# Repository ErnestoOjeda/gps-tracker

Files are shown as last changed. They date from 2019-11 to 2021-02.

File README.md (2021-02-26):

# wander-hardware

### Overview

The Wander v1.1 prototype is an adaptation of the Particle LTE line of industrialized cellular IoT modules. It is based on the Particle E-Series LTE module and includes an onboard GPS module based on the MTK-3339 chipset.

### Description

#### Front

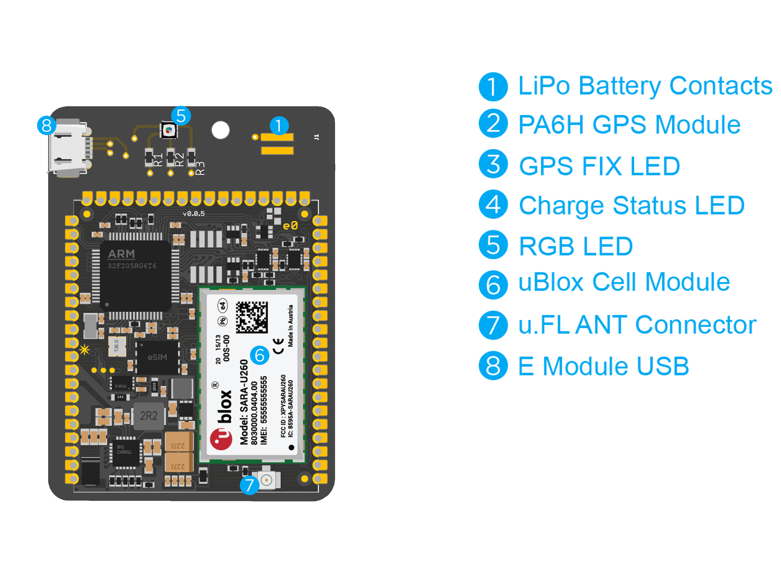
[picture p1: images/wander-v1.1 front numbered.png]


#### Back

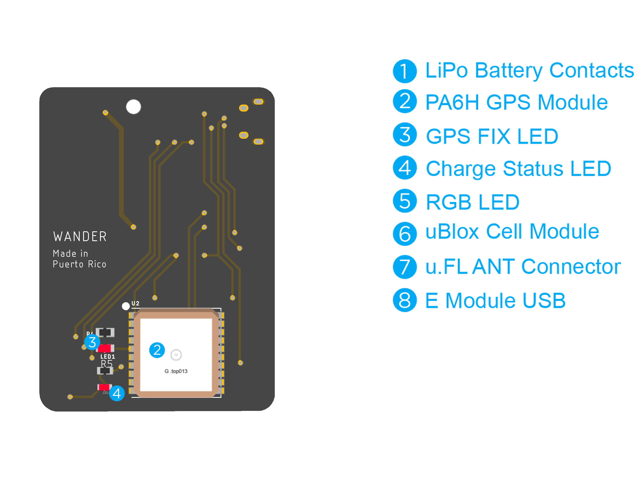
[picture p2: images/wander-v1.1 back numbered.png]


| ID 					 | Description |
|:---|:---|
| **LiPo Battery Contacts** | This is directly connected to the LIPO pin. The recommended input voltage range on this pin is between 3.6V to 4.4VDC. Make sure that the battery can handle currents of at least 3Amp.  |
| **PA6H GPS module** |MTK-3339-based GPS module that can track up to 22 satellites on 66 channels, with an excellent -165 dB sensitivity receiver, and a built in antenna.|
| **GPS FIX LED** | This LED blinks at about 1Hz while it's searching for satellites and blinks once every 15 seconds when a fix is found to conserve power.|
| **Charge status LED** | Pretty self-explanatory.|
| **RGB LED** | Displays cellular connectivity status.|
| **u-blox cell module** | This is the u-blox SARA module.|
| **uFl antenna connector** |Plug the antenna here. |
| **E Module USB port** | This is the module's microUSB port that connects to the STM32F microcontroller.|

### Components List

* u-blox SARA R410M LTE modem
  * LTE CAT M1/ NB1 module with global hardware support
  * 3GPP Release 13 LTE Cat M1
* MediaTek MTK3339
  * SBAS, Galileo, GLONASS, GPS / QZSS
  * Supports WAAS/EGNOS/MSAS/GAGAN
  * 22 tracking / 66 acquisition-channel GPS receiver
* STMElectronics LSM303ADRTR
  * 3 magnetic field channels and 3 acceleration channels
  * Embedded temperature sensor
* STMicroelectronics STM32F205RGT6 
  * 120MHz ARM Cortex M3 microcontroller
  * 1MB flash, 128KB RAM 
  * Supports DSP instructions, hardware accelerated FPU calculations 
* MAX17043 fuel gauge
* Micro USB 2.0 full speed (12 Mbps)
* FCC and PTCRB certified
* RoHS compliant (lead-free)

### Structure of this Repository
 - /bom
     + Contains the electronics bill of materials outlining the components used
 - /cad-cases
     + Contains .f3d files for various looks-like/works-like case designs
 - /datasheets
     + Contains the relevant datasheets of the components used
 - /documentation
     + Contains prototype PRD and Working Specification & Requirements sheets
 - /eagle
     + Contains the schematic and PCB files in the Eagle file format
 - /gerbers
     + Contains PCB gerber files for manufacturing
 - /images
     + Contains the images used in the description

### Change Log
#### v1.1.0 (LATEST)
* initial beta release

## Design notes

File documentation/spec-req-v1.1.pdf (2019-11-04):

# Wander v1.1 Prototype Sheet

Wander Team 2019

# Requirements

## - Commercial/Regions/Regulatory

- COGS $200; sold in US and Canada. FCC (active emitter), IC, PTCRB, CE, RoHS LeadFree

## - Hardware/Sensors

- Block diagram, major BOM components; sensor requirements (accelerometer)

## - Electronics/Power/Battery

- PCB must be no larger than 100mm x 36mm, 2K EEPROM; no more than 1.8A transients at 5VDC, 130uA in deep sleep; max battery runtime 11 days in deep sleep, LiPo, no larger than 51mm x 34mm x 9mm

## - Firmware/API/Libraries

- Operating System (Device OS), OTA updates (Particle Cloud); CoAP over DTLS over UDP; RSA used for authentication

## - Software/Web/Cloud

- Device Cloud, Google Firebase

## - Mechanical/Plastics/Logos/Packaging

- PA-12 enclosure; Wander logo embossed onto enclosure surface

## - Environmental/ Dimensions/Service

- Operating ambient temperature -20C-60C, 0% - 95% RH; 80mm x 45mm x 15mm; no field service, issues will be resolved in-house as refurbish

# Specifications

## - Installed System Life

- N/A

## - Operating Temperature Range

- -40 to 85C E-Series; -40 to 85C PA6H; -20 to 60C LiPo Battery

## - Dimensions

- Main Housing
■ 80mm x 45mm x 20mm
- PCB
■ 58mm x 42mm x 11mm
- Battery
■ 41mm x 41mm x 6mm

## - Weight

- TBD

## - On-Board GPS

- 66-channel, MTK3339-based module
- GPS/QZSS L1 C/A, GLONASS L10F, BeiDou B1I, Galileo E1B/C, SBAS L1 C/A: WAAS, EGNOS, MSAS, GAGAN
- Update rates: Single GNSS: up to 10 Hz, 2 Concurrent GNSS: up to 10 Hz
- -165dBm sensitivity; 20mA current draw; 1.8m position accuracy
- Acquisition times: Cold starts: 34s, Aided starts: 2s, Reacquisition: 1s

## - Battery

- Runtime: 28h
- Cell Chemistry: Rechargeable Lithium Ion Polymer (Lithium Systems)
- Polymer Cell Electrolyte: Gel Polymer
- Dimensions: 41mm x 41mm x 6mm
- Capacity: 1080mAh; JP604141

## - Power

- USB: Max 500mA supply
- VIN: 3.9VDC to 12VDC, rated 10W
- LiPo: 180mA, upto 550mA transients. Deep sleep mode at 110uA

## - Field Strategy

- Not field serviceable
- RMA strategy not necessary, test units will be swapped out for working units
- No reset button

## - Wireless Firmware Update

- Done OTA on the Particle Device Cloud

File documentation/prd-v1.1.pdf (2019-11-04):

### Product Requirements Document (v1.1)

### OVERVIEW

Product Description

Market Need | Parents with children too young to own a cell phone can get location information and notifications-based insight of their children’s whereabouts while on vacation. Currently-available solutions are either expensive, require ownership & data-contracts, or impractical.
Key Features/ Functionality | GPS-over-cellular and location analytics coupled with human-based notifications that offers: ● Out-of-the-box connectivity ● App-based or notification-based location ● Insights into child’s location history
Other Product Compatibility, Ecosystem, etc. | ● Cellular Connectivity ● GNSS Compatibility ● Mobile App ● Manual sources of information (humans)

Stakeholders

Target User | Children ages 4 to 10 years old, the elderly, and people looking to track their assets while out on vacation.
Target Purchaser (if different from user) | Parents, Guardians, Owners/Proprietors
Other Stakeholders | TBD

### COMMERCIALS AND REGULATORY

Countries of Sale | United States
Target Launch Date | Q4 2019

Regulatory Requirements

Safety (UL, CE) | Battery operated -- not required
Emissions (FCC, CE) | Pre-certified Modules ● uBlox SARA R410M ● Generic MTK3339
Interoperability (Cellular, WiFi) | Cellular LTE-M

Labeling

Regulatory Marks | FCC; identifier displayed on cellular module
Country of Origin | Made in China
Serial Number | Serial Number with QR code displayed on cellular module

Financials

BOM Cost | N/A
COGs | $196.80
MSRP | Free; on a rental-by-the-hour basis
Acceptable Margin | 55% target margin; $26,000 target P/L per Device

Volume

MOQ of First Production Run | 10
Annual Volume | N/A
Timeline for Product Refresh (EOL) | 2 to 3 weeks depending on testing outcome and user feedback

### ENVIRONMENT

Storage Environment

Temperature Range | -30C to 75C
Humidity Range | 0% to 95% RH

Operating Environment

Indoor, Outdoor, Wearable | Indoor, Outdoor, Contained Unit
Temperature Range | -40C to 85C
Humidity Range | 0% to 95% RH

### INDUSTRIAL DESIGN

Brand | Push a button, find your kid.

Picture

Color, Material, and Finish (CMF) | Nylon 12 -- (gray, dyed)
Logo size and placement | Embossed into top surface of the enclosure
Connectors (Power, USB, Lighting, Audio) | Micro-USB
Visual Interface (Screen size and type, LEDs) | Red charging LED, RGB status LED, red GPS FIX LED
Touch Interface (Mechanical actuators/switches, touch sensitivity, haptics) | None
Audio Interface (Microphones, speakers) | None

### SOFTWARE ARCHITECTURE AND DATA PROCESSING

Block Diagram of Data Flow

### ELECTRICAL HARDWARE AND SENSORS

Block Diagram of Electrical Hardware

Input/Sensor Requirements | None
Output/Actuator Requirements | None
Critical BOM Components | ● Cellular Module ● GNSS Module ● Battery
Communication Requirements | CoAP over DTLS over UDP; 397ms round-trip
Power Requirements | ● Rechargeable Li-Poly Battery ● 28hr Runtime ● 1080mAh

### DURABILITY

Lifetime requirements | 3500 uses; ~4 years
Cycles of various sub-systems | ≥ 500 battery charge cycles
Chemical Resistance | Superior (PA12)
UV resistance (sunlight) | Superior (PA12)
Environmental (Dust, Water, etc.) | IP68
Mechanical (Drop, Vibration, Abrasion, etc.) | The device must withstand a fall from 15ft onto concrete in six different orientations

### PACKAGING

In the Box | ● Pre-assembled E-Series LTE + Adafruit GPS MTK339 ● Battery (1080mAh) ● Taoglas Ultra Wide Band Antenna
Unboxing Experience | No packaging and custom installation necessary
Printing, colors, inserts, cardboard type, drop requirements | None
Retail Requirements | N/A (sold at kiosk)
SKU Combinations | 1

### SERVICEABILITY

Repair Services | Full replacement handled by the team
Returns Process | Users can contact the team for any grievances regarding the product
Repair/Return Qualifications/Tolerances | Faulty product is subject to replacement and refurbishment
Customer Support System | Phone, text, or email

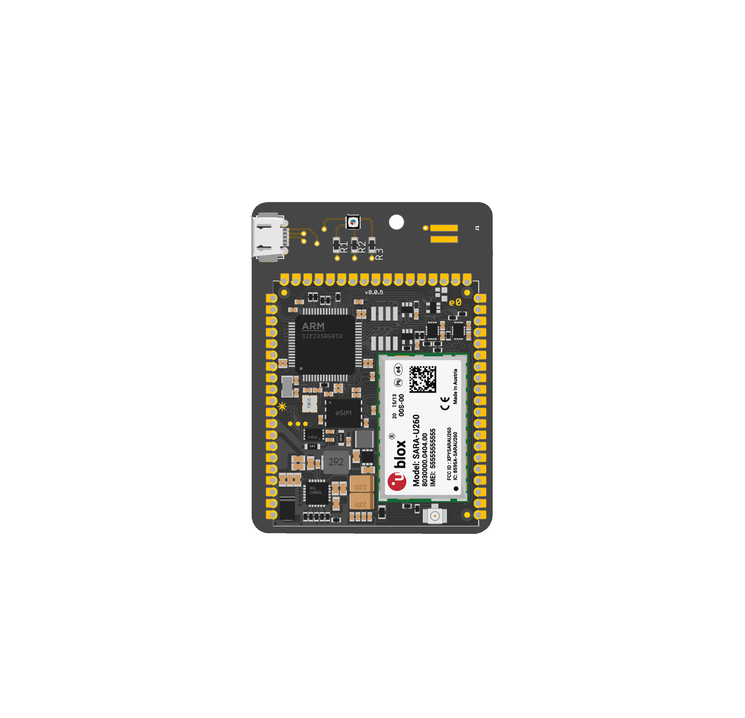
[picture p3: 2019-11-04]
images/wander-v1.1 front.png

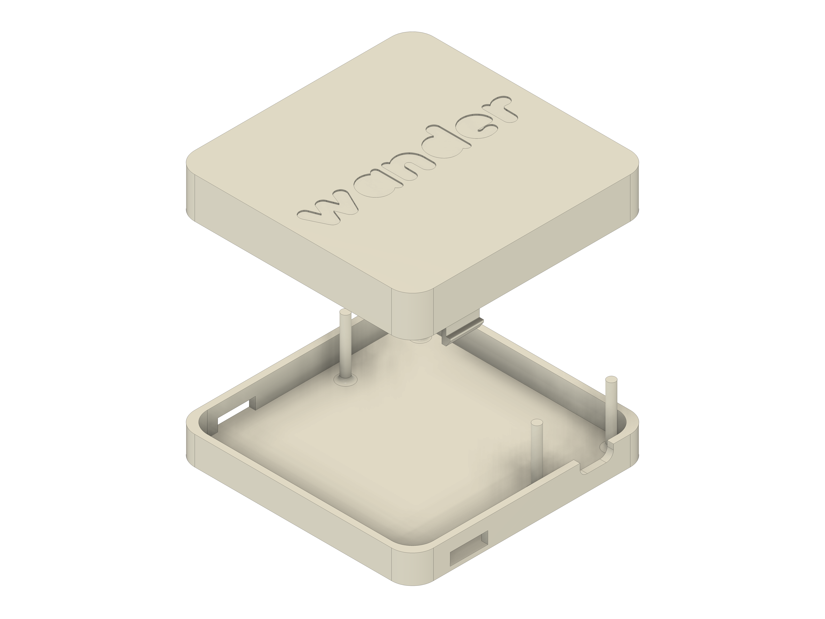
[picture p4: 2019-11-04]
cad/cases/wl-3/wander-wl3.png

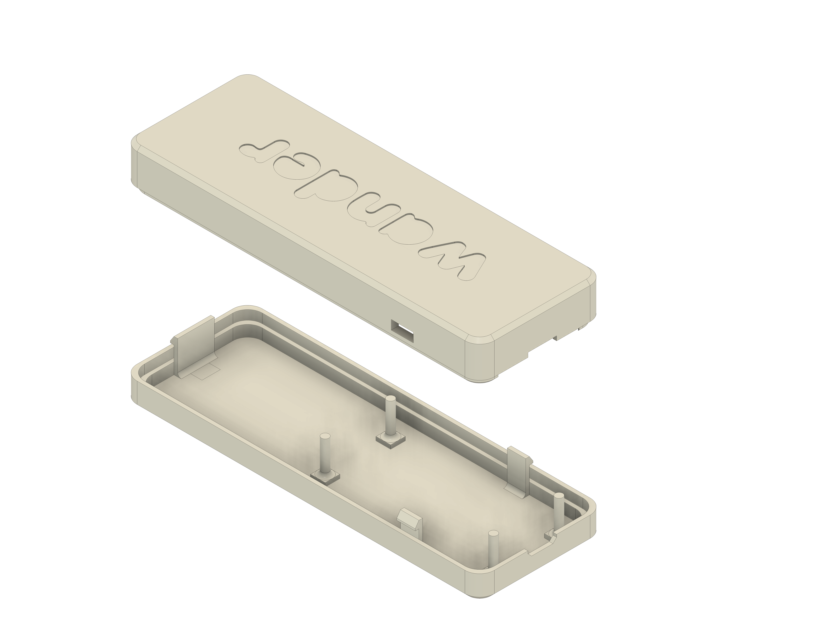
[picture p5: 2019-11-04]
cad/cases/wl-1/wander-wl1.png

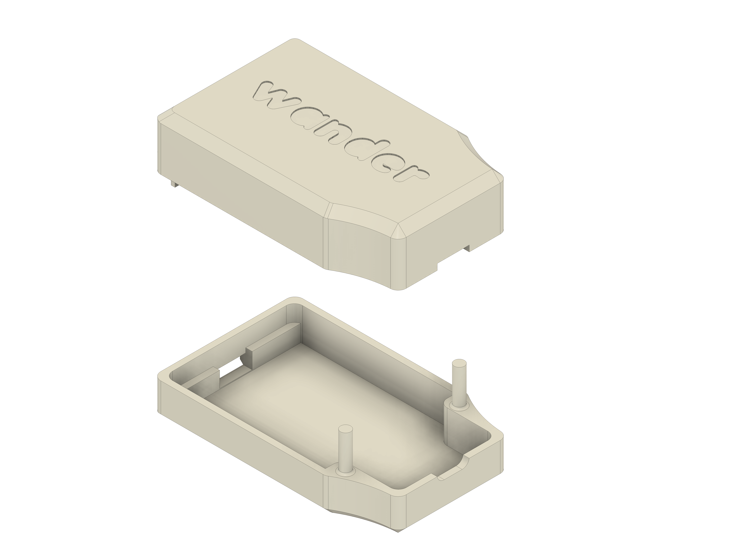
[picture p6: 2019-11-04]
cad/cases/wl-2/wander-wl2.png

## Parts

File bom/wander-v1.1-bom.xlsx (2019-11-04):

IDENTIFIER | DESCRIPTION | VALUE | V | A | W | TOL | PACKAGE ID | DESIGNATOR | QTY | MANUFACTURER | MANUFACTURER P/N | NOTES
CONNECTOR | LIPO BATTERY CONNECTOR |  |  |  |  |  | JST-2-SMD | J1 | 1 | KAWEEI | CW2001-02T1-H01-D
CONNECTOR | MICRO USB CONNECTOR |  |  |  |  |  |  | X1 | 1 | KAWEEI | CMCUSB-5BFM14X-01-X
LED | LED | RED LED |  |  |  |  |  | LED1 | 1 | OSRAM | LS M67K-H2L1-1-Z
LED | LED | RED LED |  |  |  |  |  | LED2 | 1 | EVERLIGHT | 19-217/R6C-AL1M2VY/3T
LED | RGB-LED-CLMVB-FKARGB | RGB LED |  |  |  |  | 4-PLCC (3.2 mm x 2.8mm) | U$6 | 1 | CREE | CLMVB-FKA-CFHEHLCBB7A363
RESISTOR | RESISTOR | 470 OHM |  |  |  | 1% |  | R4 | 1 | Panasonic | ERJ-6ENF4700V
RESISTOR | RESISTOR | 1K |  |  |  | 5% | 603 | R1, R2, R3, R5 | 4 | Unihom | RS-03K102JT

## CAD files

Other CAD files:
cad/cases/wl-1/wander-wl1.f3d
cad/cases/wl-2/wander-wl2.f3d
cad/cases/wl-3/wander-wl3.f3d

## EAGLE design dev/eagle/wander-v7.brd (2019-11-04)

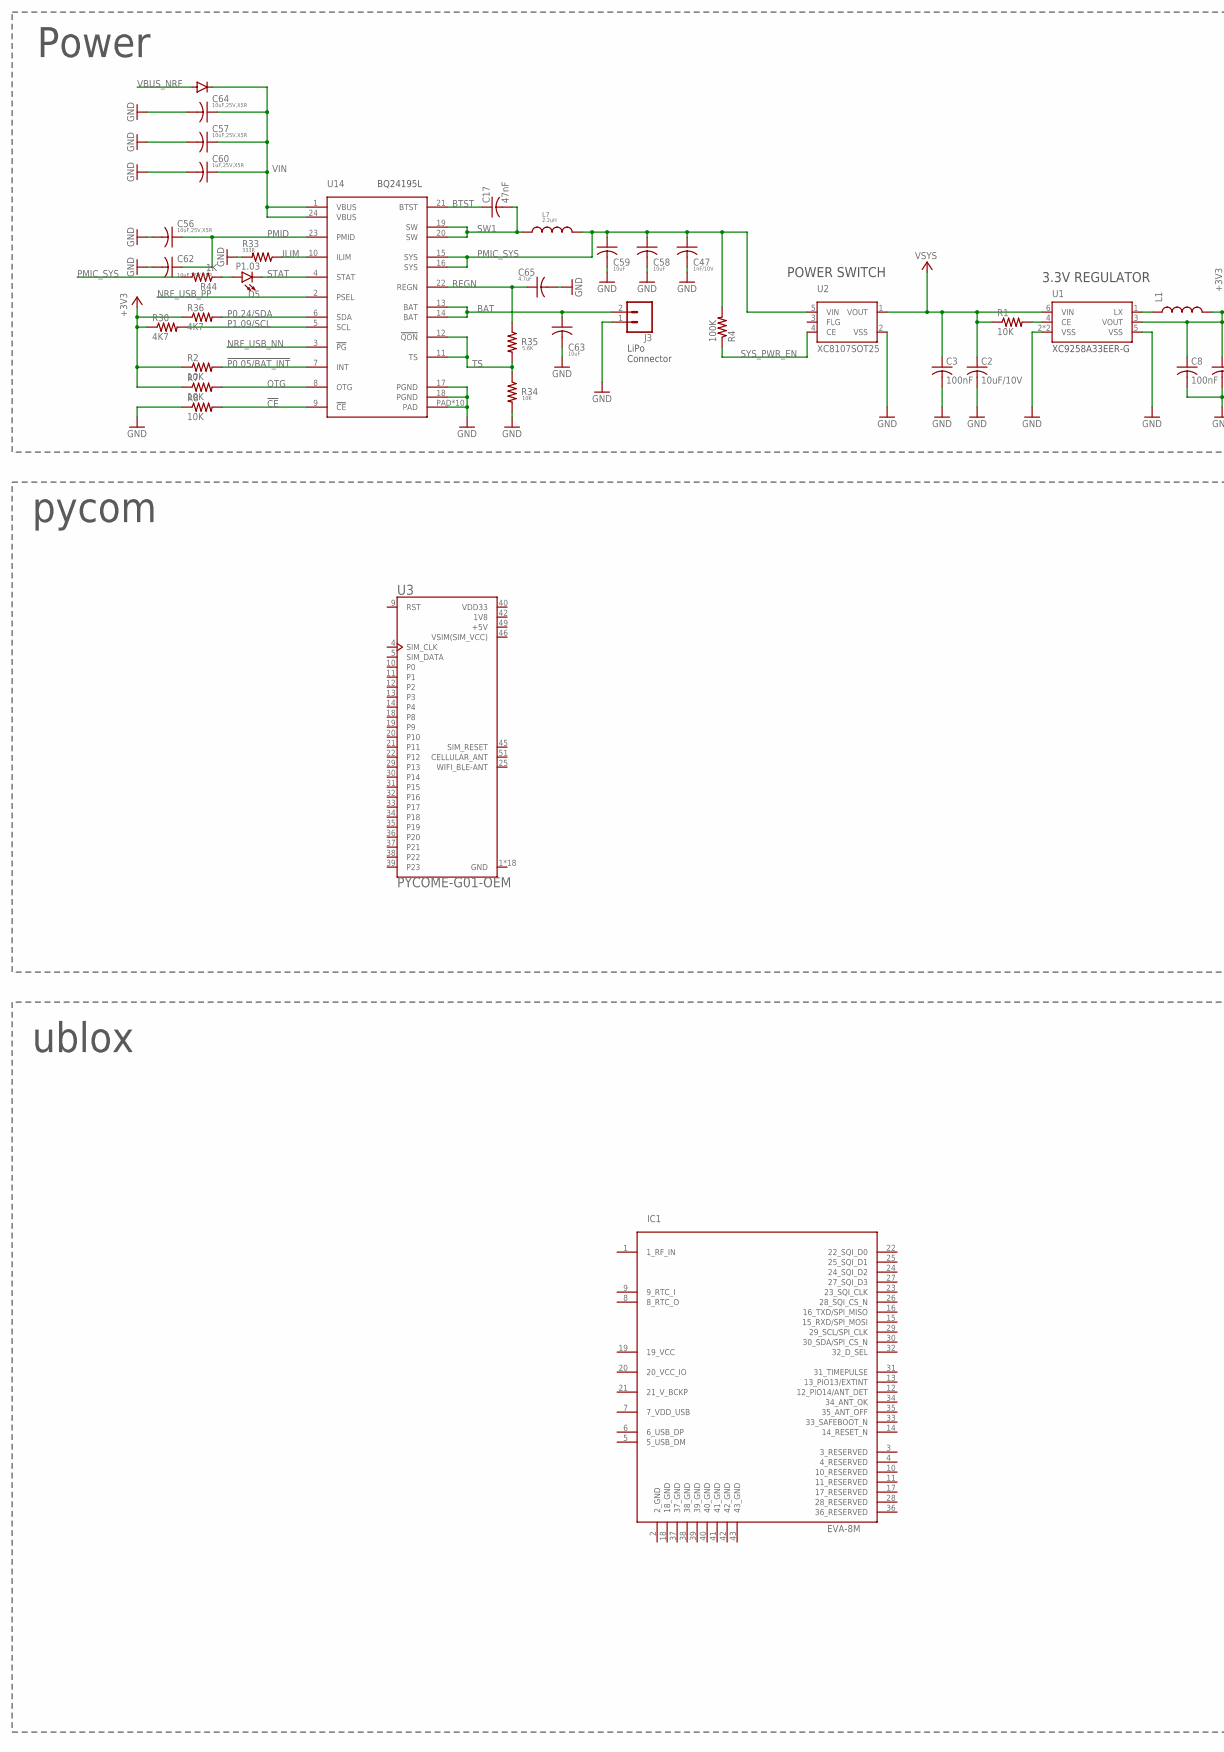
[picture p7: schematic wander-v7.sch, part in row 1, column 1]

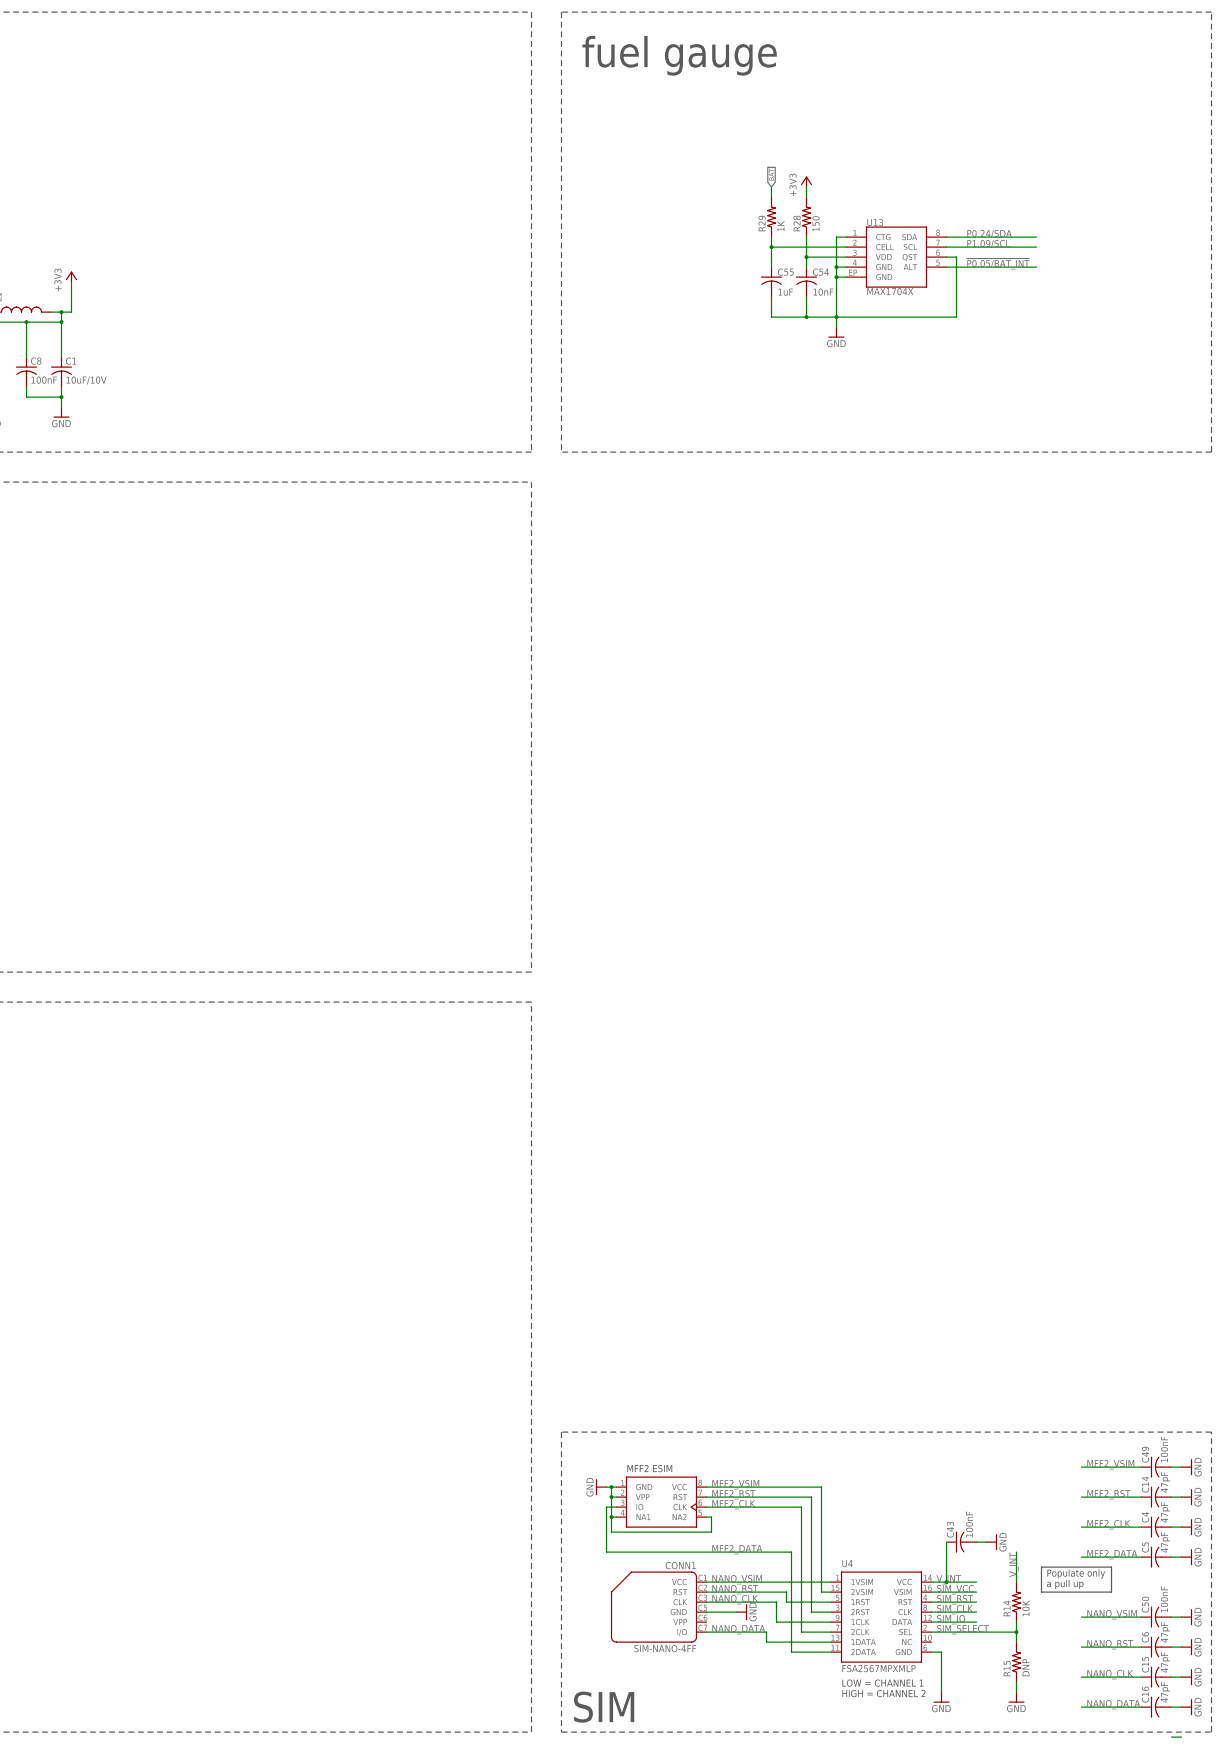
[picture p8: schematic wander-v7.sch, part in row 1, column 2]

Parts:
C1, C2: 10uF/10V; C0603K
C3: 100nF; C0603K
C4, C5, C6, C14, C15, C16: 47pF; C0201_B
C8, C43, C49, C50: 100nF; C0201_B
C17: 47nF; C0201_B
C47: 1nF/10V; C0402_B
C54: 10nF; C0402_B
C55: 1uF; C0402_B
C56, C57, C62, C64: 10uF,25V,X5R; C0603_B
C58, C59, C63: 10uF; C0603_B
C60: 1uF,25V,X5R; C0603_B
C65: 4.7uF; C0603_B
CONN1: SIM-NANO-4FF; GCT-SIM8100
D4: DIODE_NT; DIODE-DO-220AA_NT(SMP)
D5: P1.03; LED-0603
IC1: EVA-8M
J3: CONN_02-JST-2MM-SMT; JST-2-SMD@2
L1: INDUCTOR-SPARKFUNVLS3012ET-4R7M; INDUCTOR-VLS-E
L7: 2.2uH; INDUCTOR-4040
R1, R2, R7, R8, R14: 10K; C0201_B
R4: 100K; C0201_B
R15: DNP; C0201_B
R28: 150; 0402-RES
R29: 1K; 0402-RES
R30, R36: 4K7; C0201_B
R33: 333R; R0402_B
R34: 10K; R0402_B
R35: 5.6K; R0402_B
R44: 1K; C0201_B
U1: XC9258A33EER-G; USP-6C
U2: XC8107SOT25; SOT25
U3: PYCOME-G01-OEM; PYCOM_PYCOME-G01-OEM
U4: FSA2567MPXMLP; MLP16
U7: ESIMSON8; MFF2
U13: MAX1704X; TDFN-8
U14: BQ24195L; QFN24

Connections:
1V8: U3.42 (1V8)
!CE: R8.2, U14.9 (!CE)
!P0.05/BAT_INT: R2.2, U13.5 (ALT), U14.7 (INT)
+3V3: C1.1, C8.1, L1.P$2 (2), R2.1, R7.1, R28.2, R30.1, R36.1, U1.3 (VOUT)
+5V: U3.49 (+5V)
BAT: C63.1, J3.2 (1), R29.2, U14.13 (BAT), U14.14 (BAT)
BTST: C17.1, U14.21 (BTST)
GND: C1.2, C2.2, C3.2, C4.2, C5.2, C6.2, C8.2, C14.2, C15.2, C16.2, C43.2, C47.2, C49.2, C50.2, C54.2, C55.2, C56.2, C57.2, C58.2, C59.2, C60.2, C62.2, C63.2, C64.2, C65.2, CONN1.C5 (GND), J3.1 (2), R8.1, R15.1, R33.2, R34.2, U1.2 (VSS), U1.5 (VSS), U1.P$1 (VSS), U2.2 (VSS), U3.1 (GND), U3.2 (GND), U3.3 (GND), U3.6 (GND), U3.7 (GND), U3.8 (GND), U3.23 (GND), U3.24 (GND), U3.26 (GND), U3.27 (GND), U3.28 (GND), U3.41 (GND), U3.43 (GND), U3.44 (GND), U3.47 (GND), U3.48 (GND), U3.50 (GND), U3.52 (GND), U4.6 (GND), U7.1 (GND), U7.2 (VPP), U7.4 (NA1), U7.5 (NA2), U13.1 (CTG), U13.4 (GND), U13.6 (QST), U13.EP (GND), U14.17 (PGND), U14.18 (PGND), U14.PAD, U14.PAD@1 (PAD), U14.PAD@2 (PAD), U14.PAD@3 (PAD), U14.PAD@4 (PAD), U14.PAD@5 (PAD), U14.PAD@6 (PAD), U14.PAD@7 (PAD), U14.PAD@8 (PAD), U14.PAD@9 (PAD)
ILIM: R33.1, U14.10 (ILIM)
MFF2_CLK: C4.1, U4.7 (2CLK), U7.6 (CLK)
MFF2_DATA: C5.1, U4.11 (2DATA), U7.3 (IO)
MFF2_RST: C14.1, U4.3 (2RST), U7.7 (RST)
MFF2_VSIM: C49.1, U4.15 (2VSIM), U7.8 (VCC)
unnamed: D5.A, R44.1
unnamed: R1.2, U1.4 (CE)
unnamed: L1.P$1 (1), U1.1 (LX)
unnamed: C54.1, R28.1, U13.3 (VDD)
unnamed: C55.1, R29.1, U13.2 (CELL)
NANO_CLK: C15.1, CONN1.C3 (CLK), U4.9 (1CLK)
NANO_DATA: C16.1, CONN1.C7 (I/O), U4.13 (1DATA)
NANO_RST: C6.1, CONN1.C2 (RST), U4.5 (1RST)
NANO_VSIM: C50.1, CONN1.C1 (VCC), U4.1 (1VSIM)
NRF_USB_NN: U14.3 (!PG)
NRF_USB_PP: U14.2 (PSEL)
OTG: R7.2, U14.8 (OTG)
P0.24/SDA: R36.2, U13.8 (SDA), U14.6 (SDA)
P1.09/SCL: R30.2, U13.7 (SCL), U14.5 (SCL)
PMIC_SYS: C47.1, C58.1, C59.1, L7.P$2 (2), R4.2, R44.2, U2.5 (VIN), U14.15 (SYS), U14.16 (SYS)
PMID: C56.1, C62.1, U14.23 (PMID)
REGN: C65.1, R35.1, U14.22 (REGN)
SIM_CLK: U4.8 (CLK)
SIM_IO: U4.12 (DATA)
SIM_RST: U4.4 (RST)
SIM_SELECT: R14.1, R15.2, U4.2 (SEL)
SIM_VCC: U4.16 (VSIM)
STAT: D5.C, U14.4 (STAT)
SW1: C17.2, L7.P$1 (1), U14.19 (SW), U14.20 (SW)
SYS_PWR_EN: R4.1, U2.4 (CE)
TS: R34.1, R35.2, U14.11 (TS), U14.12 (!QON)
VBUS_NRF: D4.ANODE
VDD33: U3.40 (VDD33)
VIN: C57.1, C60.1, C64.1, D4.CATHODE, U14.1 (VBUS), U14.24 (VBUS)
VSIM(SIM_VCC): U3.46 (VSIM(SIM_VCC))
VSYS: C2.1, C3.1, R1.1, U1.6 (VIN), U2.1 (VOUT)
V_INT: C43.1, R14.2, U4.14 (VCC)

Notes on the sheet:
MFF2 ESIM
Populate only a pull up
3.3V REGULATOR
LiPo Connector
ublox
pycom
Power
SIM
fuel gauge
LOW = CHANNEL 1 HIGH = CHANNEL 2
POWER SWITCH

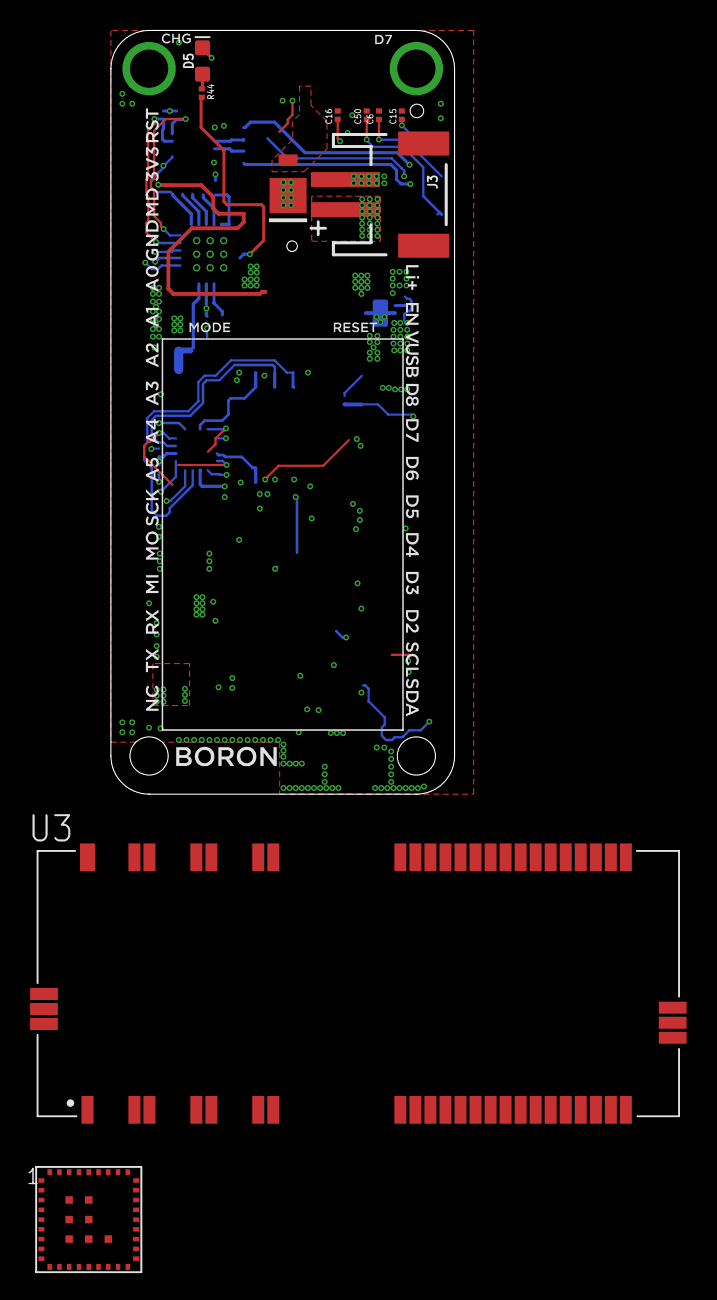
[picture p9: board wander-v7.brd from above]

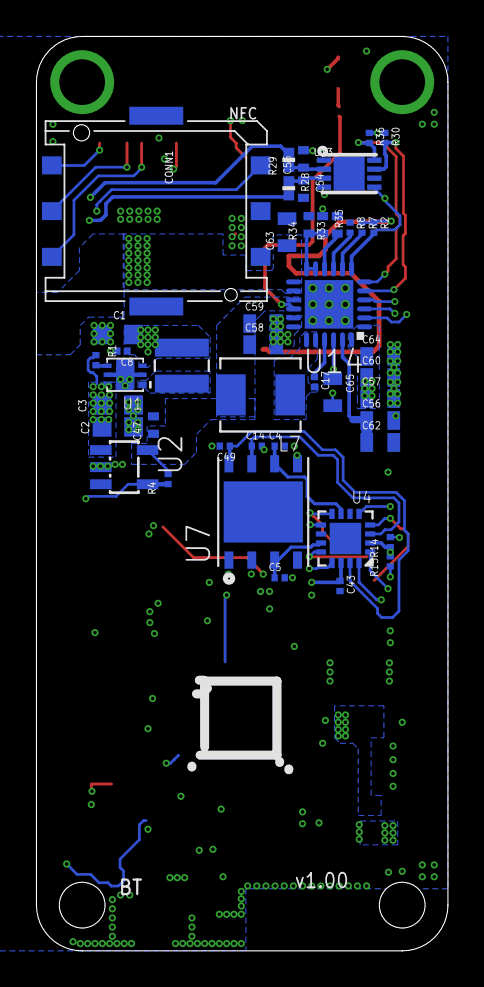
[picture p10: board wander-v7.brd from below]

Board: 8 copper layers, 22.9 x 50.8 mm, 55 parts (45 on the bottom side), 34 nets.

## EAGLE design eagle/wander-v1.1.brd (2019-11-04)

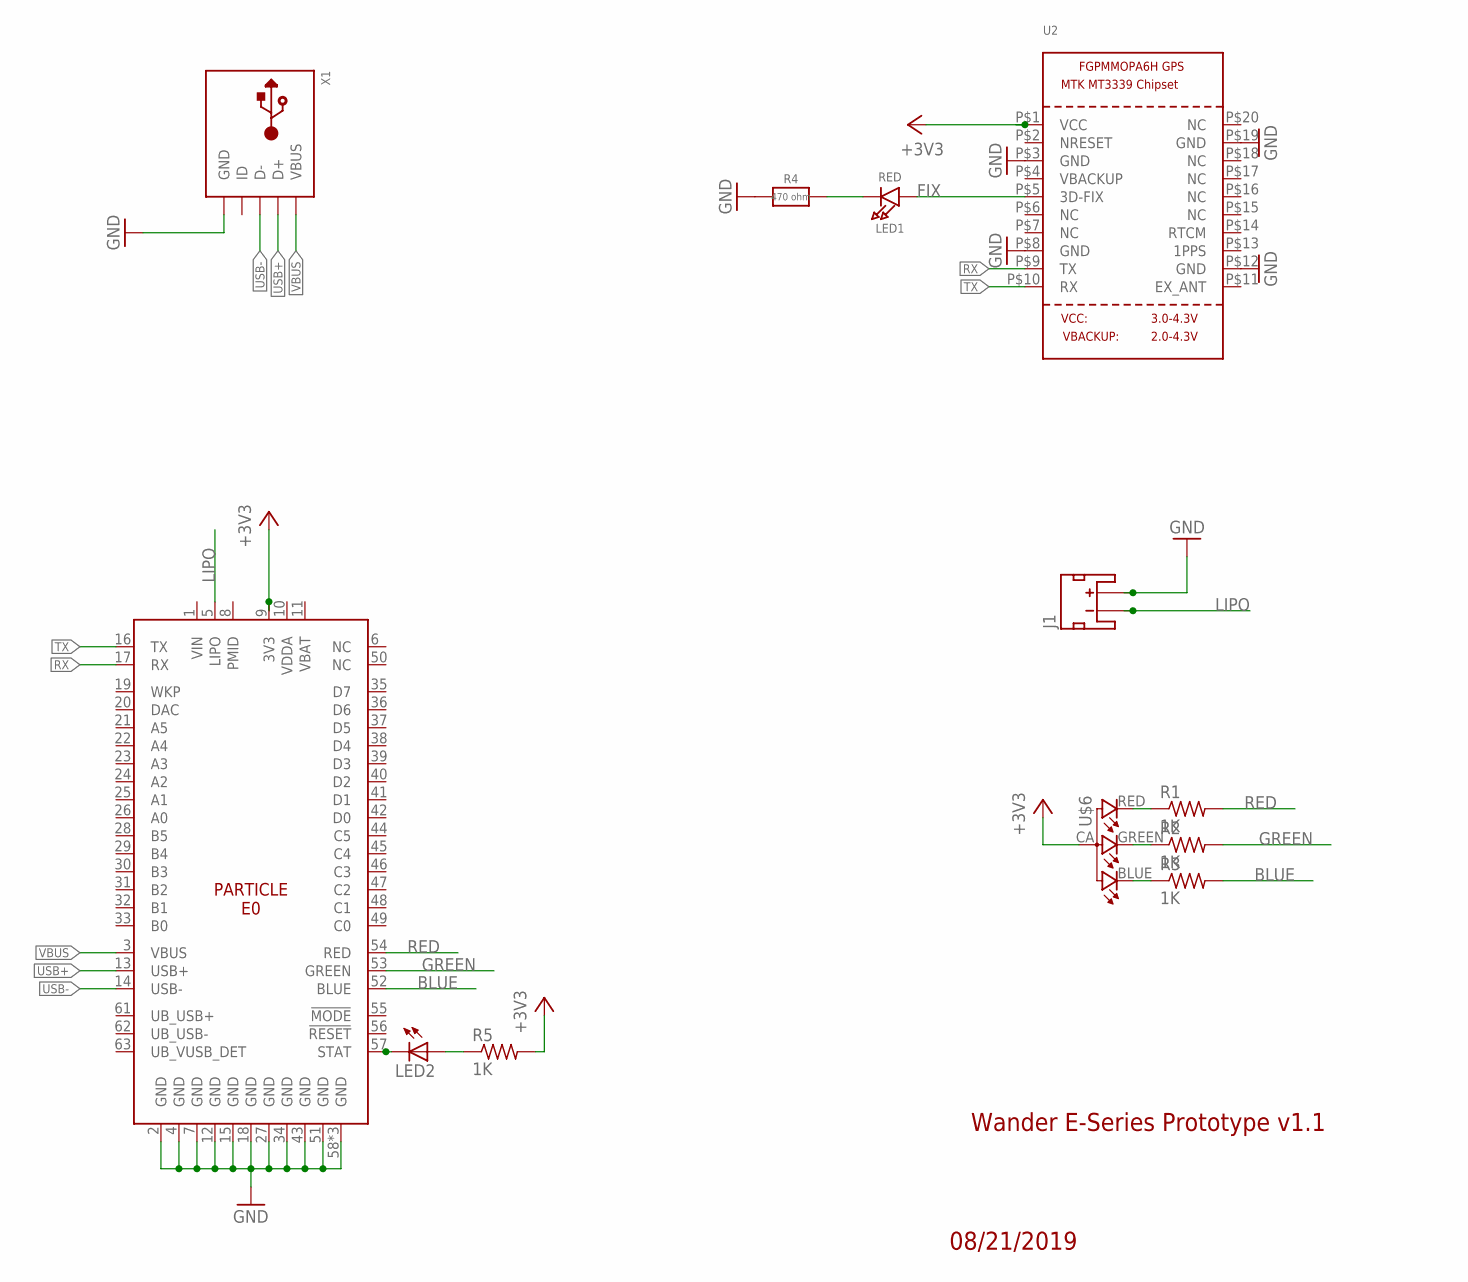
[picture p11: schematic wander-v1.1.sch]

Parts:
J1: JST_2MM_MALE; JST-2-SMD
LED1: RED; CHIPLED_0805_NOOUTLINE
LED2: LED0603; LED-0603
R1, R2, R3, R5: 1K; R0603
R4: 470 ohm; 0805-NO
U1: E0_V005; E0
U2: GPS_FGPMMOPA6H; FGPMMOPA6H
U$6: RGB-LED-CLMVB-FKARGB; PLCC4-2MM-RGB
X1: USB-NEW-PHOTON; 4UCONN_CMCUSB-5BFM14X-01-X

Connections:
+3V3: R5.2, U1.9 (3V3), U2.P$1 (VCC), U$6.CA (1)
BLUE: R3.2, U1.52 (BLUE)
FIX: LED1.A, U2.P$5 (3D-FIX)
GND: J1.2 (+), R4.1, U1.2 (GND), U1.4 (GND), U1.7 (GND), U1.12 (GND), U1.15 (GND), U1.18 (GND), U1.27 (GND), U1.34 (GND), U1.43 (GND), U1.51 (GND), U1.58 (GND), U1.59 (GND), U1.60 (GND), U2.P$3 (GND), U2.P$8 (GND), U2.P$12 (GND), U2.P$19 (GND), X1.P$1 (GND), X1.P$6 (GND), X1.P$7 (GND), X1.P$8 (GND), X1.P$9 (GND), X1.P$10 (GND), X1.P$11 (GND)
GREEN: R2.2, U1.53 (GREEN)
LIPO: J1.1 (-), U1.5 (LIPO)
unnamed: R1.1, U$6.RED (4)
unnamed: R2.1, U$6.GREEN (3)
unnamed: R3.1, U$6.BLUE (2)
unnamed: LED1.C, R4.2
unnamed: LED2.A, R5.1
unnamed: LED2.C, U1.57 (STAT)
RED: R1.2, U1.54 (RED)
RX: U1.17 (RX), U2.P$9 (TX)
TX: U1.16 (TX), U2.P$10 (RX)
USB+: U1.13 (USB+), X1.P$3 (D+)
USB-: U1.14 (USB-), X1.P$4 (D-)
VBUS: U1.3 (VBUS), X1.P$5 (VBUS)

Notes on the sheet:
08/21/2019
Wander E-Series Prototype v1.1

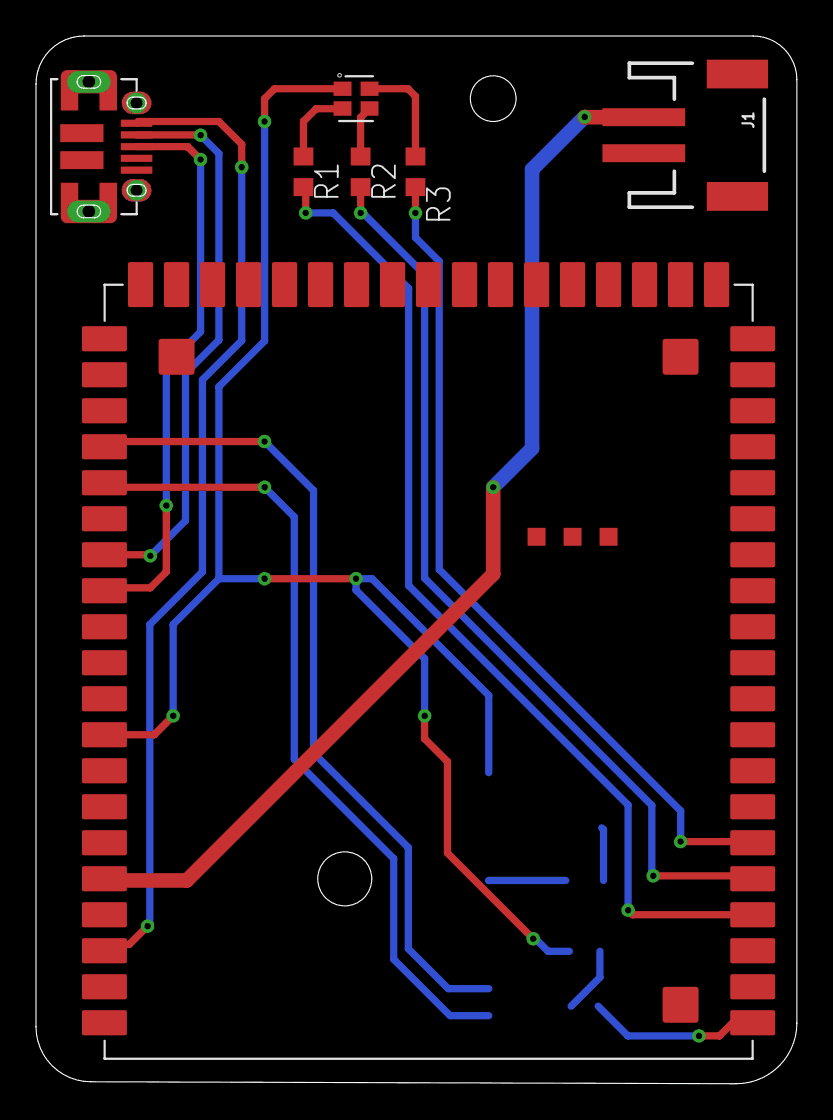
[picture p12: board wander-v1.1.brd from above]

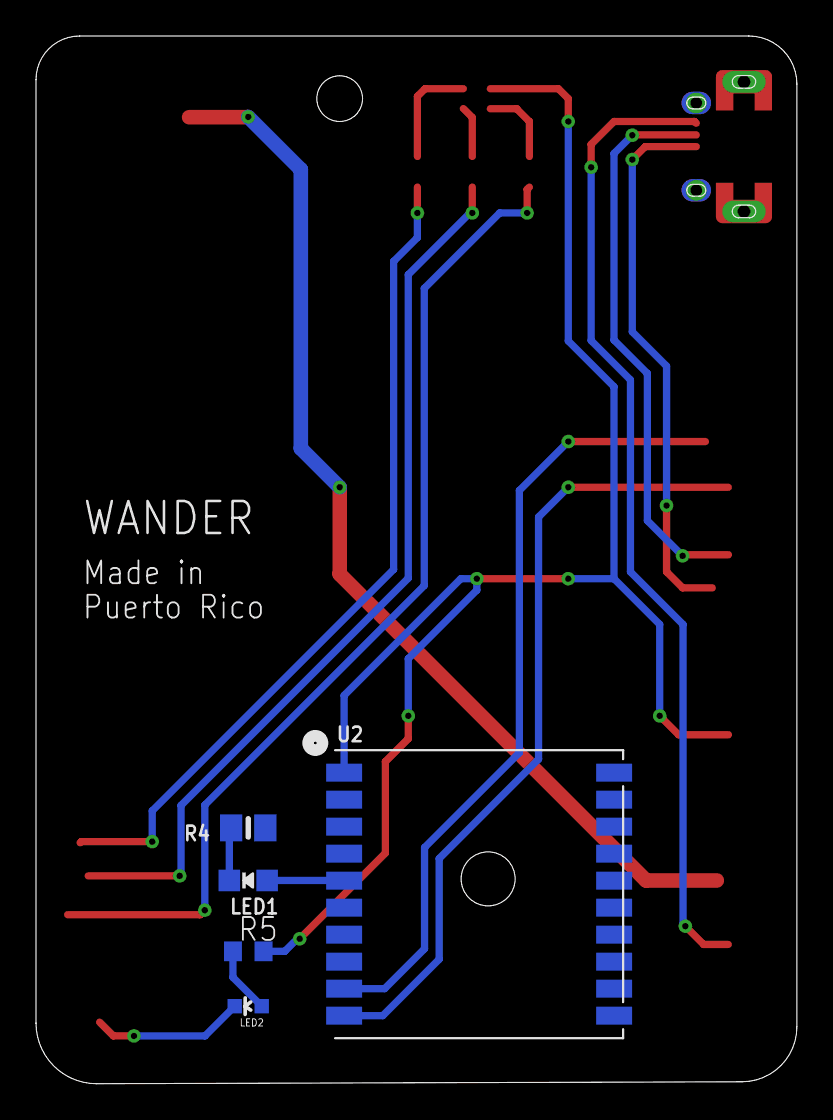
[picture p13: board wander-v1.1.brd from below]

Board: 2 copper layers, 42.3 x 58.2 mm, 12 parts (5 on the bottom side), 18 nets.

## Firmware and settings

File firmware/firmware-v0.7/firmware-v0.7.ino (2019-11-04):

/*************************************************************************
 * Main Stable Version of Wander Firmware - Particle E-series Tailored (M3)
 *************************************************************************
 *
 * Features:
 *  - Logistic that is able to know when to do a push of data
 *  - Refresh Actual Location
 *  - Sends dataObject to a firebase, curently:
 *    ** battery_life
 *    ** sat_fix
 *    ** latitude
 *    ** longitude
 *    ** altitude
 *    ** course
 *    ** speed
 *    ** # of satellites lock
 *
 * Particle Functions
 *  - actual-location => Just refresh and send an updated dataObject to firebase
 *  - debug-device [true,false] => Can be used to call a device into debug mode
 *
 * @version 0.7
 */
float wander_os_version = 0.7;

/**************************** CONFIGURE BELOW ****************************/
/*************************************************************************/

/**
 * Enable/Disable for debugging purposes. Uses Particle Console.
 *
 * You can also perform a particle API call for debug-device with a true parameter And
 * it will enable the debug-mode, meaning you'll see whats happening on a code level.
 */
    uint8_t DEBUG = false;

/**
 * How many minutes will need to pass before each dataObject push to firebase
 *
 * If debug is enabled it will automatically go to 1 min push
 * 
 * For this to work, you'll need to ad ==> || sat_fix == true && millis() > start_timer + (60000*push)
 * on the main loop
 */
    const uint8_t data_push = 15;

/************************* VARIABLES & LIBRARIES *************************/
/*************************************************************************/

/**
 * LIBRARIES
 */
    #include <TinyGPS++.h>

/**
 * LIBRARY CALLS
 */
    FuelGauge   fuel;
    TinyGPSPlus gps;

/**
 * SETTINGS & MEMORY
 */

    // Device
    bool refresh_location = false;
    int  battery_life;

    // Minutes before dataObject Push
    uint8_t push = data_push;

    // GPS Satellites Lock
    bool sat_fix = false;

    // GPS Data
    float start_timer = 0;

    double latitude;
    double longitude;
    double altitude;
    double course;
    double speed;
    double satellites;

/****************************** SETUP & LOOP *****************************/
/*************************************************************************/

void setup() {
    // Wait for hardware serial to appear
    while (!Serial1);

    /********************* Enable the GPS Module *************************/
    Serial1.begin(9600);

    /********************* Establishing the Timer ************************/
    start_timer = millis();

    /********************* We Subscribe to Actual Location Function API Calls ************************/
    Particle.function("actual-location", get_actual_location);

    /********************* We Subscribe to Debug Function API Calls ************************/
    Particle.function("debug-device", debug_device);

    /***************************** DEBUG *********************************/
    if( DEBUG ) {
        Particle.publish("DEBUG", "Initializing Particle ID: " + System.deviceID(), PRIVATE);
        Particle.publish("DEBUG", "Wander OS Version: " + String(wander_os_version), PRIVATE);

        // Changing push to debug Module
        push = 1;
    }
}

/*************************************************************************/

void loop() {

    /**
     * PROCCESS GPS DATA
     *
     * For the E-series to be able to access the data it will need to get it
     * Using the serial channel and add it to the TinyGPSPlus library to manage it
     * We break the loop once we get the gps data...meanwhile is going to keep looking for satellites
     */
    while (Serial1.available() > 0) {
        if (gps.encode(Serial1.read())) {
            if ( gps.location.isValid() ) {
                break;
            }
            else {
                Particle.publish("Debug", "Searching for satellites...", PRIVATE);
                sat_fix = false;
                delay(10000);
            }
        }
    }

    /**
     * SEND DATA TO CLOUD
     *
     * We limit the time of every push to the first one, once the device is started
     * Or if we ask for a refresh of the location... => [refresh_location == true]
     */
    if( sat_fix == false && millis() > start_timer + (60000) || refresh_location == true ) {

        /********************** Resetting the Timer *************************/
        start_timer = millis();

        if( DEBUG ) {
            Particle.publish("DEBUG", "Preparing the data...", PRIVATE);
        }

        /************************* Battery Life *****************************/
        battery_life = fuel.getSoC();
        battery_life = map(battery_life, 0, 80, 0, 100);

        /************************* Get the GPS data *****************************/
        if ( gps.location.isValid() ) {
            latitude   = gps.location.lat(); // In degrees (double)
            longitude  = gps.location.lng(); // In degrees (double)
            altitude   = gps.altitude.feet(); // or .meters() or .miles() or .kilometers() | (double)
            course     = gps.course.deg(); // (double)
            speed      = gps.speed.mph(); // or .knots() or .mps() or .kmph()  | (double)
            satellites = gps.satellites.value();

            // We indicate that we have the gps data
            sat_fix = true;
        }

        /********************* Send data to the cloud *************************/
        if( sat_fix == true ) {
            // Send the event to Particle Cloud
            particle_cloud_push( battery_life, "true", latitude, longitude, altitude, course, speed, satellites );
            
            // Because we now have sent a valid location, we reset the request
            refresh_location = false;
        }
        else {
            // Only Used for debug purposes currently
            if( DEBUG ) {
                particle_cloud_push( battery_life, "false", 0, 0, 0, 0, 0, 0 );
            }
        }
    }
}

/*************************************************************************/
/**************************** DO NOT EDIT BELOW **************************/
/*************************************************************************/

int get_actual_location(String command) {
    refresh_location = true;

    /***************************** DEBUG *********************************/
    if( DEBUG ) {
      Particle.publish("DEBUG", "Requesting Actual Location...", PRIVATE);
    }
}

/*************************************************************************/

int debug_device(String command) {
    if(command == "true") {
        DEBUG = true;

        // Changing push to debug Mode
        push = 1;

        Particle.publish("DEBUG", "DEBUG mode enabled", PRIVATE);
    }
    else {
        DEBUG = false;

        // Changing push to standard Mode
        push = data_push;

        Particle.publish("DEBUG", "DEBUG mode disabled", PRIVATE);
    }
}

void particle_cloud_push( double battery_life, char* sat_fix, double latitude, double longitude, double altitude,
                         double course, double speed, double satellites ) {
    Particle.publish("wander-hardware-push", "{\"batteryLife\":\"" +  String(battery_life) + "\", \"satFix\": \"" + String(sat_fix) + "\", \"gpsData\": { \"latitude\": \"" + String(latitude) +
                                                                                                                          "\", \"longitude\": \"" + String(longitude) +
                                                                                                                          "\", \"altitude\": \"" + String(altitude) +
                                                                                                                          "\", \"course\": \"" + String(course) +
                                                                                                                          "\", \"speed\": \"" + String(speed) +
                                                                                                                          "\", \"satellites\": \"" + String(satellites) + "\" } }", PRIVATE);
}

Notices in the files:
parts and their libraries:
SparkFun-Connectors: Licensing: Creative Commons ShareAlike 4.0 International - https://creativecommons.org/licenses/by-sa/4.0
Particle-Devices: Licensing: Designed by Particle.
